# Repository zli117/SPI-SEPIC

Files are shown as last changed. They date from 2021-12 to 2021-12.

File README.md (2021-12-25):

# SPI-SEPIC
SPI controlled SEPIC boost buck converter.

Input voltage range: 5\~24V
Output voltage range: 2.5\~24V

## Schematic

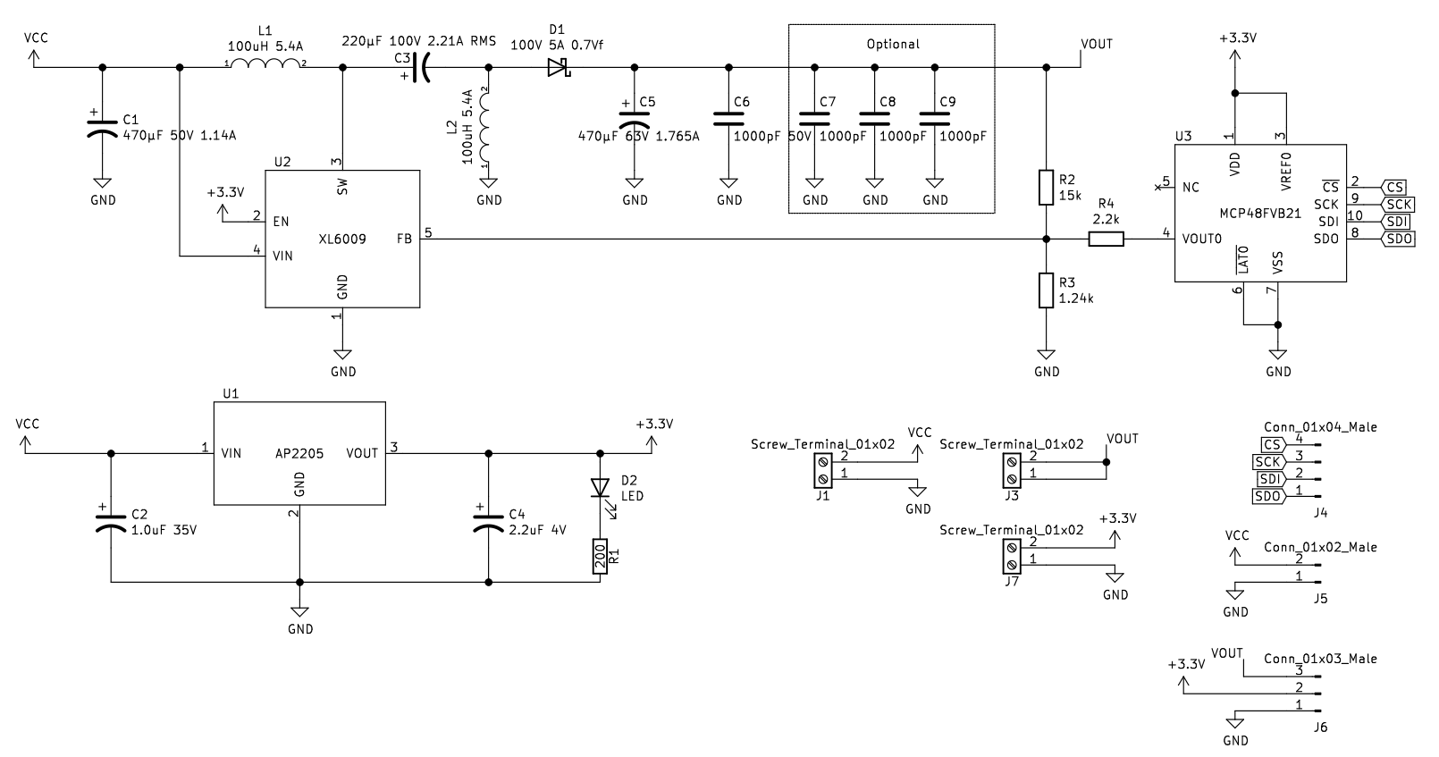
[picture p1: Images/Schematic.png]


## PCB

Front                         |  Back
:----------------------------:|:----------------------------:
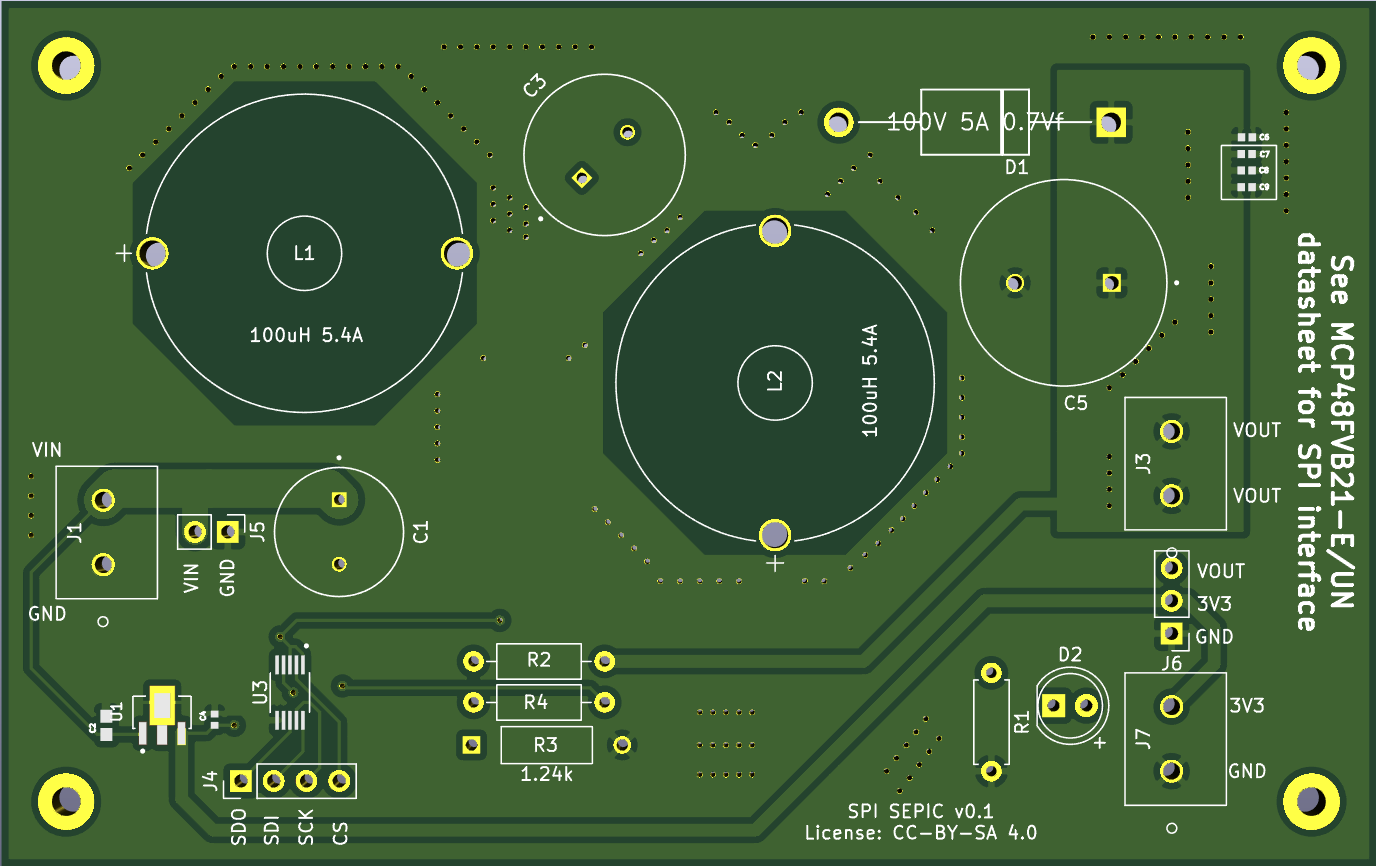
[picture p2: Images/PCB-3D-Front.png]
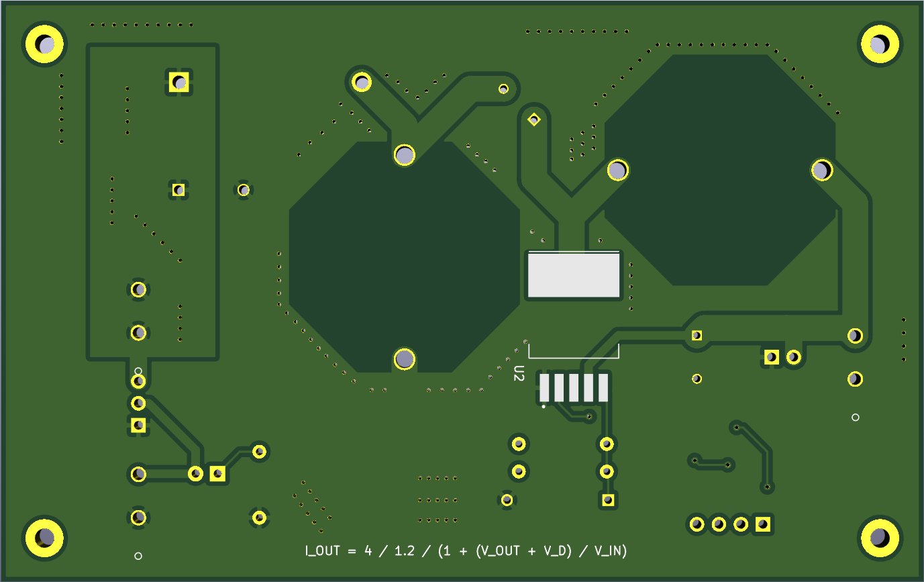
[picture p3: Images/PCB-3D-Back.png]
  |  
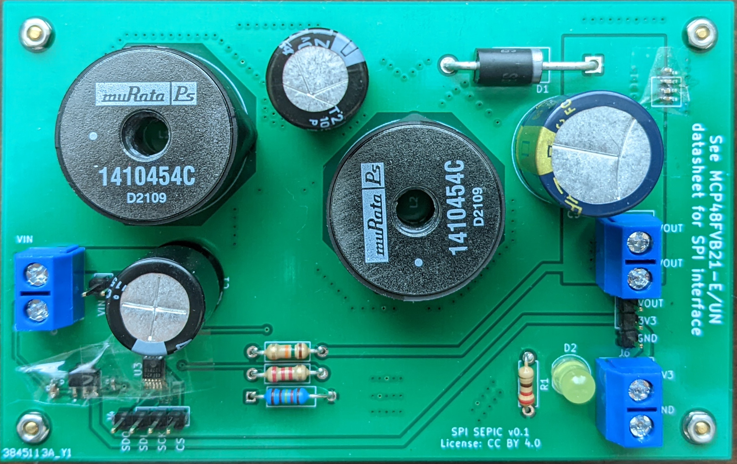
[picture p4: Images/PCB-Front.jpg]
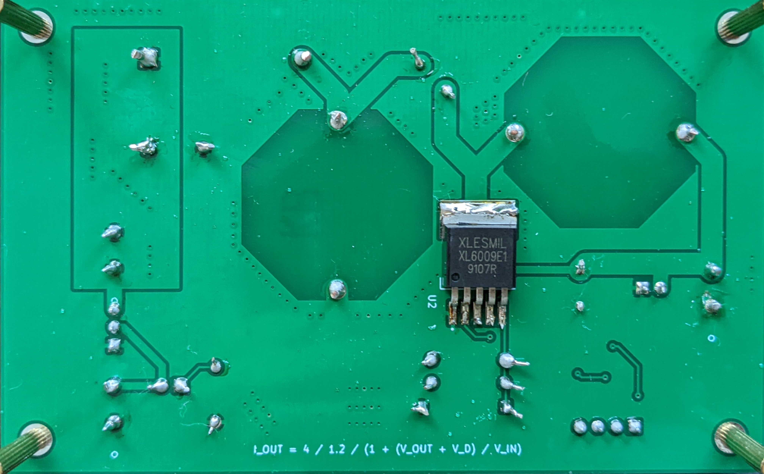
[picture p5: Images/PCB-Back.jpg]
     |  

## Parts

Ref # | Name | Link
:---:|:-----:|:----:
R1 | 220 Resister | Generic Part
R2 | 15k Resister | https://www.digikey.com/en/products/detail/koa-speer-electronics-inc/CF1-4CT52R153J/13537263
R3 | 1.24k Resister | https://www.digikey.com/en/products/detail/yageo/MFR-25FBF52-1K24/13029
R4 | 2.2k Resister | https://www.digikey.com/en/products/detail/koa-speer-electronics-inc/CF1-4CT52R222J/13537295
U1 | AP2205-33Y-13 | https://www.digikey.com/en/products/detail/diodes-incorporated/AP2205-33Y-13/10107162
U2 | XL6009 | https://www.haoyuelectronics.com/Attachment/XL6009/XL6009-DC-DC-Converter-Datasheet.pdf
U3 | MCP48FVB21-E/UN | https://www.digikey.com/en/products/detail/microchip-technology/MCP48FVB21-E-UN/5773466
D1 | SB5H100-E3/73 | https://www.digikey.com/en/products/detail/vishay-general-semiconductor-diodes-division/SB5H100-E3-73/9600329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
D2 | 5mm LED | Generic Part
C1 | UVR1H471MHD1TO | https://www.digikey.com/en/products/detail/nichicon/UVR1H471MHD1TO/4328413
C2 | CGA3E1X7R1V105M080AC | https://www.digikey.com/en/products/detail/tdk-corporation/CGA3E1X7R1V105M080AC/4931462
C3 | 100ZLJ220M12.5X25 | https://www.digikey.com/en/products/detail/rubycon/100ZLJ220M12-5X25/3133967
C4 | C1005X6S0G225K050BC | https://www.digikey.com/en/products/detail/tdk-corporation/C1005X6S0G225K050BC/3951112
C5 | EEU-FC1J471 | https://www.digikey.com/en/products/detail/panasonic-electronic-components/EEU-FC1J471/266361
C6 C7 C8 C9 | 04025C102KAT2A | https://www.digikey.com/en/products/detail/kyocera-avx/04025C102KAT2A/563211
L1 and L2 | 1410454C | https://www.digikey.com/en/products/detail/murata-power-solutions-inc/1410454C/1924845

## SPI Command

See [MCP48FVBXX doc](https://ww1.microchip.com/downloads/en/DeviceDoc/20005466A.pdf) for the full details. For simple writes, send the following 24-bit command: 

Let `val` be the value of the 12-bit DAC. Value in range `[0, 4096)`)

Byte 0 | Byte 1 | Byte 2
:---:|:-----:|:----:
All 0 | `val >> 8` | `val & 0xFF`

Note that due to part tolerances, you might need to calibrate the mapping with max output voltage (`val = 4095`) and min output voltage (`val = 0`)

## Change Log

 * v0.1: Initial version

This work is licensed under a
[Creative Commons Attribution-ShareAlike 4.0 International License][cc-by-sa].

[][cc-by-sa]

[cc-by-sa]: http://creativecommons.org/licenses/by-sa/4.0/
[cc-by-sa-image]: https://licensebuttons.net/l/by-sa/4.0/88x31.png
[cc-by-sa-shield]: https://img.shields.io/badge/License-CC%20BY--SA%204.0-lightgrey.svg

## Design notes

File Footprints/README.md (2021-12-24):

# Footprint and Sources

 * XL6009: https://www.snapeda.com/parts/XL6009/XLSEMI/view-part/?t=XL6009
 * SB5H100-E3: https://www.allaboutcircuits.com/electronic-components/datasheet/SB5H100-E354--Vishay/
 * MCP48FVB21-E: https://www.snapeda.com/parts/MCP48FVB21-E/UN/Microchip/view-part/?t=MCP48FVB21
 * AP2205-33Y-13: https://www.snapeda.com/parts/AP2205-50Y-13/Diodes%20Incorporated/view-part/?t=AP2205
 * CGA3E1X7R1V105M080AC: https://www.snapeda.com/parts/CGA3E1X7R1V105M080AC/TDK/view-part/?t=CGA3E1X7R1V105M080AC
 * C1005X6S0G225K050BC: https://www.snapeda.com/parts/C1005X6S0G225K050BC/TDK/view-part/?t=C1005X6S0G225K050BC
 * 1410454C: https://app.ultralibrarian.com/details/E6AE43DD-1072-11E9-AB3A-0A3560A4CCCC/Murata/1410454C
 * 100ZLJ220M12.5X25: https://www.snapeda.com/parts/100ZLJ220M12.5X25/Rubycon/view-part/?t=100ZLJ220M12
 * UVR1H471MHD1TO: https://www.snapeda.com/parts/UVR1H471MHD1TO/Nichicon/view-part/?t=UVR1H471MHD1TO
 * 04025C102KAT2A: https://www.snapeda.com/parts/04025C102KAT2A/AVX/view-part/?t=04025C102KAT2A
 * EEU-FC1J471: https://www.snapeda.com/parts/EEU-FC1J471/Panasonic/view-part/?t=EEU-FC1J471

SnapEDA footprints are licensed under CC-BY-SA 4.0. Others without a clear license are assumed to be CC-BY-SA 4.0

Other parts are from either [KiCad Footprints Library](https://gitlab.com/kicad/libraries/kicad-footprints) or [digikey-kicad-library](https://github.com/Digi-Key/digikey-kicad-library). Both are under license of CC-BY-SA 4.0

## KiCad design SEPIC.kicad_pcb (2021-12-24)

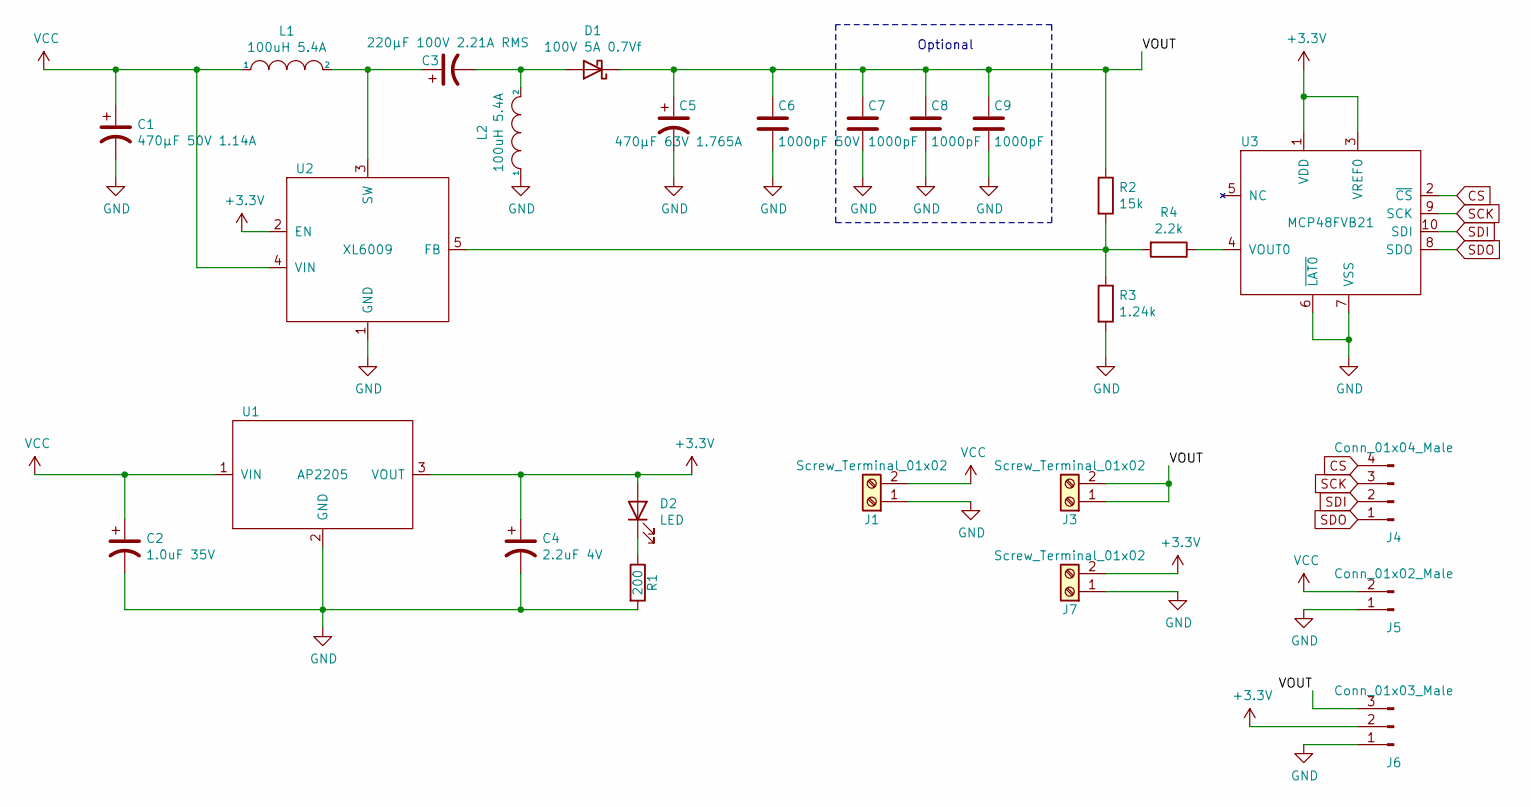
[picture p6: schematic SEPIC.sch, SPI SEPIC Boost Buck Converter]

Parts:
C1: 470µF 50V 1.14A; UVR1H471MHD1TO
C2: 1.0uF 35V; CGA3E1X7R1V105M080AC
C3: 220µF 100V 2.21A RMS; 100ZLJ220M12.5X25
C4: 2.2uF 4V; C1005X6S0G225K050BC
C5: 470µF 63V 1.765A; EEU-FC1J471
C6: 1000pF 50V; 04025C102KAT2A
C7, C8, C9: 1000pF; 04025C102KAT2A
D1: 100V 5A 0.7Vf; SB5H100-E3
D2: LED; LED_D5.0mm
J1, J3, J7: Screw_Terminal_01x02; 691137710002
J4: Conn_01x04_Male; PinHeader_1x04_P2.54mm_Vertical
J5: Conn_01x02_Male; PinHeader_1x02_P2.54mm_Vertical
J6: Conn_01x03_Male; PinHeader_1x03_P2.54mm_Vertical
L1, L2: 100uH 5.4A; 1410454C
R1: 200; R_Axial_DIN0207_L6.3mm_D2.5mm_P7.62mm_Horizontal
R2: 15k; CF1_4CT52R153J
R3: 1.24k; MFR-25FBF52-1K24
R4: 2.2k; CF1_4CT52R222J
U1: AP2205; AP2205-33Y-13
U2: XL6009
U3: MCP48FVB21; MCP48FVB21-E

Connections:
+3V3: C4.1, D2.2 (A), J6.2, J7.2, U1.3 (VOUT), U2.2 (EN), U3.1 (VDD), U3.3 (VREF0)
/VOUT: C5.1, C6.1, C7.1, C8.1, C9.1, D1.1 (K), J3.1, J3.2, J6.3, R2.1
CS: J4.4, U3.2 (~CS)
GND: C1.2, C2.2, C4.2, C5.2, C6.2, C7.2, C8.2, C9.2, J1.1, J5.1, J6.1, J7.1, L2.1, R1.2, R3.2, U1.2 (GND), U2.1 (GND), U3.6 (~LAT0), U3.7 (VSS)
unnamed: C3.1, L1.2, U2.3 (SW)
unnamed: C3.2, D1.2 (A), L2.2
unnamed: D2.1 (K), R1.1
unnamed: R2.2, R3.1, R4.2, U2.5 (FB)
unnamed: R4.1, U3.4 (VOUT0)
SCK: J4.3, U3.9 (SCK)
SDI: J4.2, U3.10 (SDI)
SDO: J4.1, U3.8 (SDO)
VCC: C1.1, C2.1, J1.2, J5.2, L1.1, U1.1 (VIN), U2.4 (VIN)

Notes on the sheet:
Optional

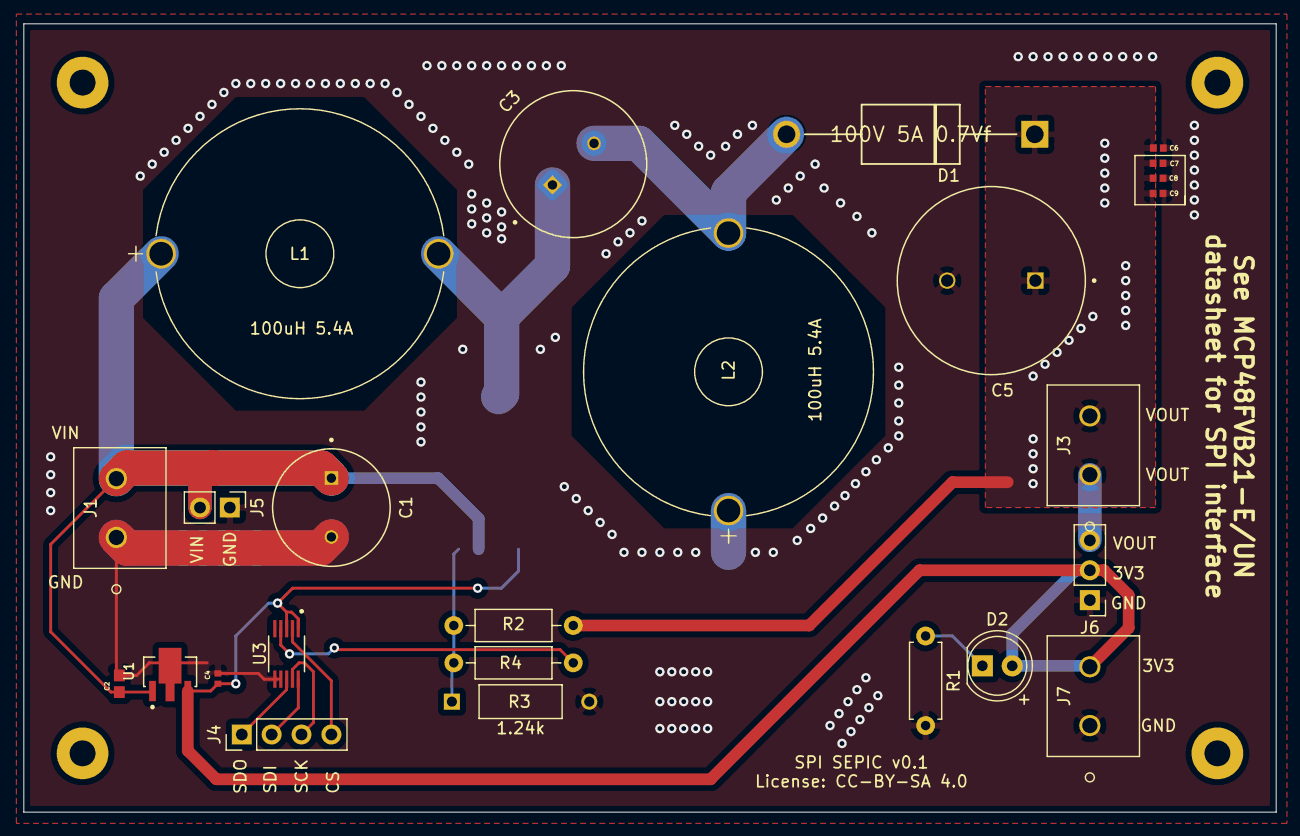
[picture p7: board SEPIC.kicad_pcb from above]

Board: 2 copper layers, 106.5 x 67.1 mm, 26 parts (1 on the bottom side), 13 nets.

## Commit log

2021-12-17 Initial commit. PCB Basic layout
    [SEPIC.kicad_pcb, SEPIC.sch]
2021-12-17 Rotated C5
    [SEPIC.kicad_pcb]
2021-12-17 Added cut line
    [SEPIC.kicad_pcb]
2021-12-17 Mostly done
    [SEPIC.kicad_pcb, SEPIC.sch]
2021-12-17 Added some optional capacitors
    [SEPIC.kicad_pcb, SEPIC.sch]
2021-12-18 Added mounting hole
    [SEPIC-B_Cu.gbl, SEPIC-B_Mask.gbs, SEPIC-B_Paste.gbp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]
2021-12-19 Updated gerber
    [SEPIC-B_Cu.gbl, SEPIC-B_Mask.gbs, SEPIC-B_Paste.gbp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]
2021-12-24 Added license related text
    [SEPIC.kicad_pcb, SEPIC.sch]

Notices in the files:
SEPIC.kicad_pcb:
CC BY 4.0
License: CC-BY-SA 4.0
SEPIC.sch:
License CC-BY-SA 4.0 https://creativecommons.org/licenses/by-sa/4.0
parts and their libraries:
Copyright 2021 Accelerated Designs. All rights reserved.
